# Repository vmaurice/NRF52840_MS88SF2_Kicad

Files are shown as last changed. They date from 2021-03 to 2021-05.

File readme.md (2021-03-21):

# NRF52840 avec le module MS88SF2

Carte schématisée et dessinée avec Kicad.

Cette carte possède le module MS88SF2 de Minew fabriqué avec un microcontrôleur NRF52840. L'objectif ici est d'avoir une carte Bluetooth faible en consommation branchée sur une batterie Lipo. 

Un module lm2902 est aussi présent afin d'amplifier les tensions de sortie des capteurs analogues.

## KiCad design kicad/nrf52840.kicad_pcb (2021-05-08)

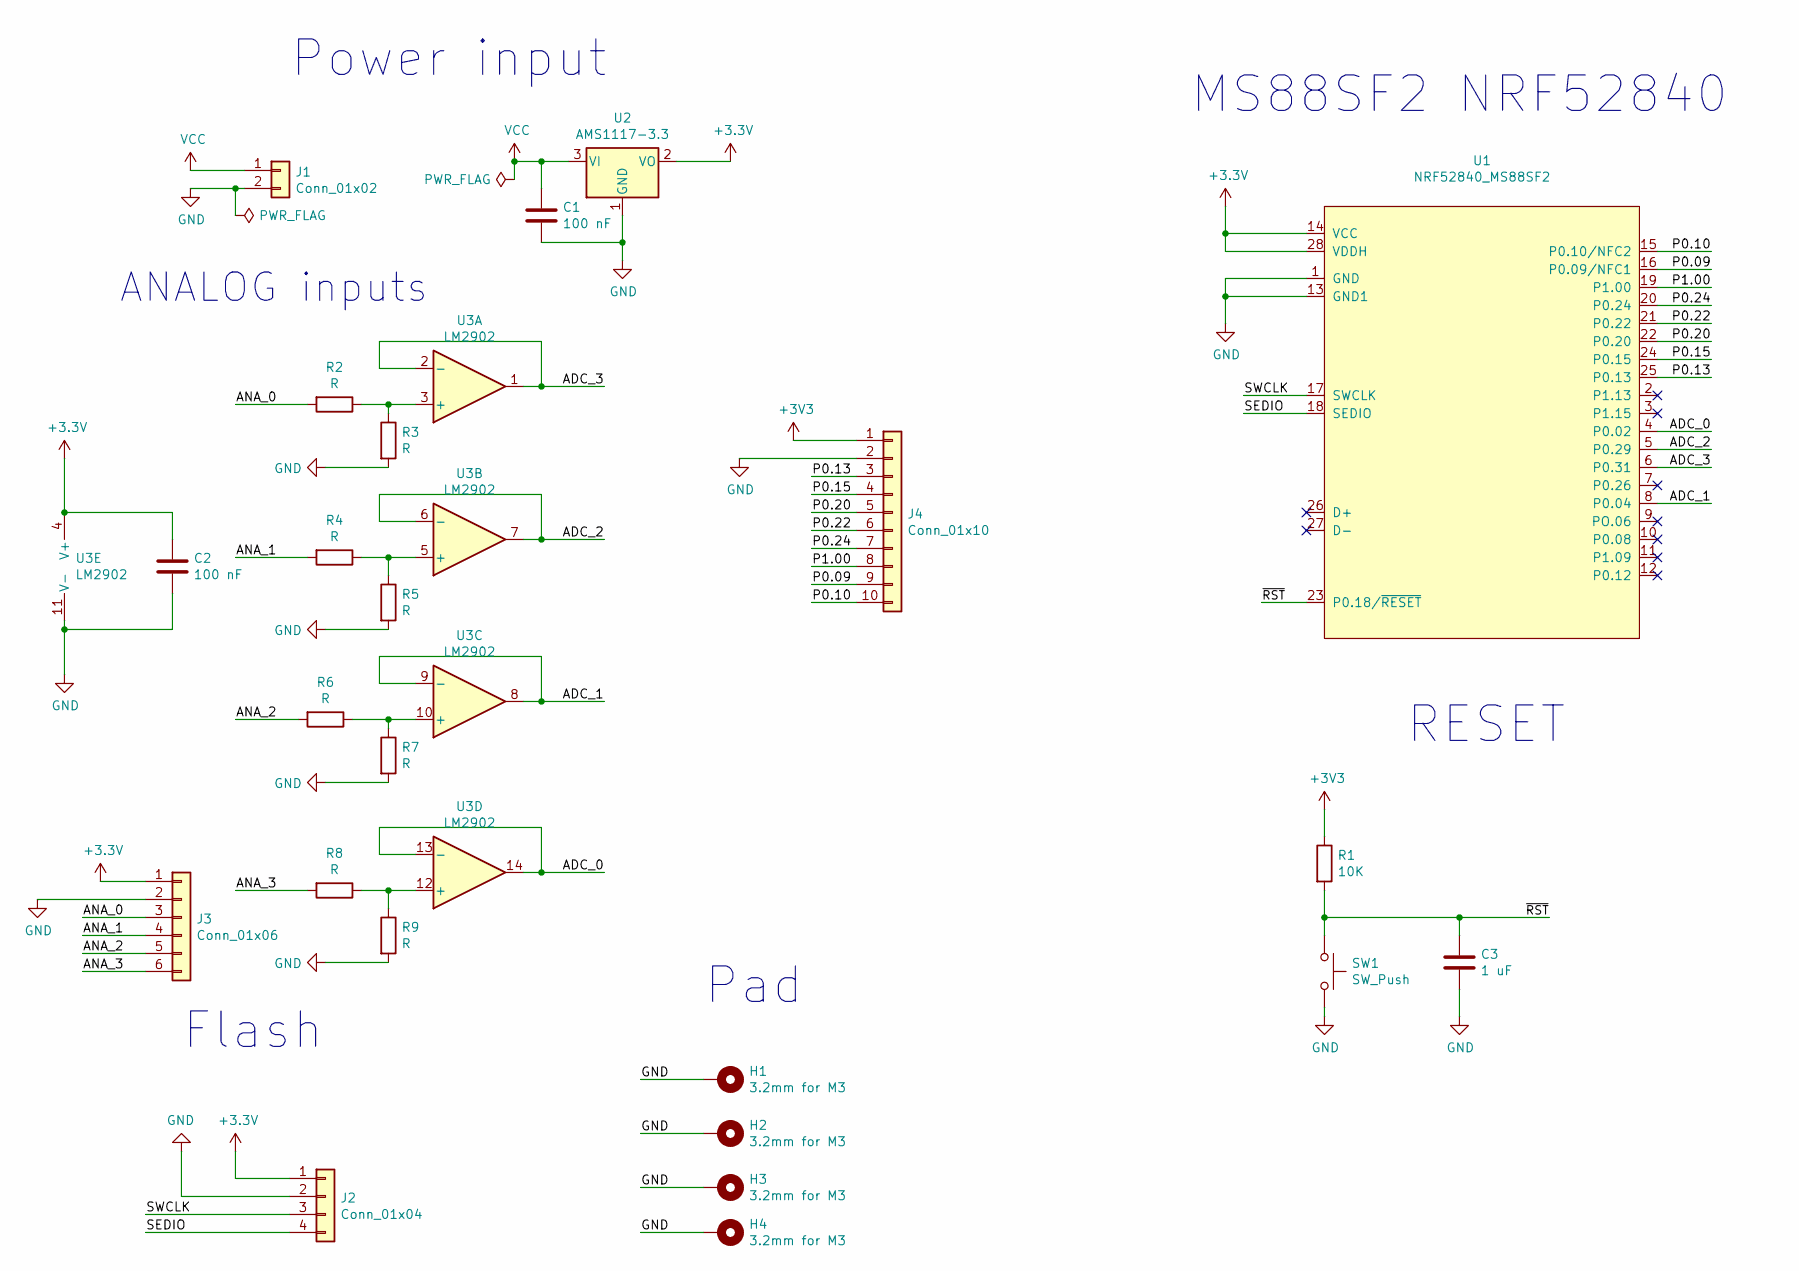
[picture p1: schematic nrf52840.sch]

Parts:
C1, C2: 100 nF; C_0805_2012Metric_Pad1.18x1.45mm_HandSolder
C3: 1 uF; C_0805_2012Metric_Pad1.18x1.45mm_HandSolder
H1, H2, H3, H4: 3.2mm for M3; MountingHole_3.2mm_M3_Pad_Via
J1: Conn_01x02; JST_XH_S2B-XH-A-1_1x02_P2.50mm_Horizontal
J2: Conn_01x04; PinHeader_1x04_P2.54mm_Vertical
J3: Conn_01x06; PinHeader_1x06_P2.54mm_Vertical
J4: Conn_01x10; PinHeader_1x10_P2.54mm_Vertical
R1: 10K; R_0805_2012Metric_Pad1.20x1.40mm_HandSolder
R2, R3, R4, R5, R6, R7, R8, R9: R; C_0805_2012Metric_Pad1.18x1.45mm_HandSolder
SW1: SW_Push; SW_SPST_SKQG_WithStem
U1: NRF52840_MS88SF2; MS88SF2
U2: AMS1117-3.3; SOT-223-3_TabPin2
U3: LM2902; SO-14_5.3x10.2mm_P1.27mm

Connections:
/ADC_0: U1.4 (P0.02), U3.13 (-), U3.14
/ADC_1: U1.8 (P0.04), U3.8, U3.9 (-)
/ADC_2: U1.5 (P0.29), U3.6 (-), U3.7
/ADC_3: U1.6 (P0.31), U3.1, U3.2 (-)
/ANA_0: J3.3, R2.2
/ANA_1: J3.4, R4.2
/ANA_2: J3.5, R6.2
/ANA_3: J3.6, R8.2
/P0.09: J4.9, U1.16 (P0.09/NFC1)
/P0.10: J4.10, U1.15 (P0.10/NFC2)
/P0.13: J4.3, U1.25 (P0.13)
/P0.15: J4.4, U1.24 (P0.15)
/P0.20: J4.5, U1.22 (P0.20)
/P0.22: J4.6, U1.21 (P0.22)
/P0.24: J4.7, U1.20 (P0.24)
/P1.00: J4.8, U1.19 (P1.00)
/SEDIO: J2.4, U1.18 (SEDIO)
/SWCLK: J2.3, U1.17 (SWCLK)
/~RST: C3.1, R1.2, SW1.1, U1.23 (P0.18/~RESET)
GND: C1.2, C2.2, C3.2, H1.1, H2.1, H3.1, H4.1, J1.2, J2.2, J3.2, J4.2, R3.2, R5.2, R7.2, R9.2, SW1.2, U1.1 (GND), U1.13 (GND1), U2.1 (GND), U3.11 (V-)
unnamed: R2.1, R3.1, U3.3 (+)
unnamed: R4.1, R5.1, U3.5 (+)
unnamed: R6.1, R7.1, U3.10 (+)
unnamed: R8.1, R9.1, U3.12 (+)
VCC: C1.1, J1.1, U2.3 (VI)

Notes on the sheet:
ANALOG inputs
MS88SF2 NRF52840
Power input
Flash
Pad
RESET

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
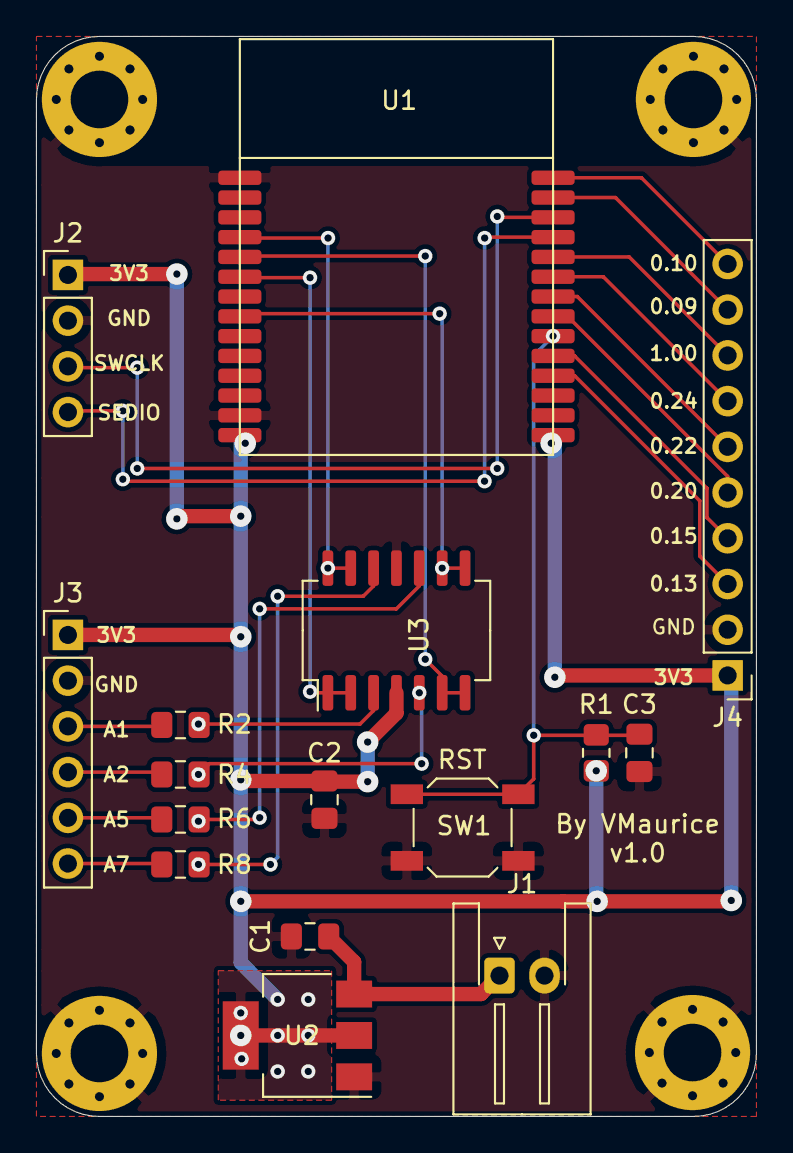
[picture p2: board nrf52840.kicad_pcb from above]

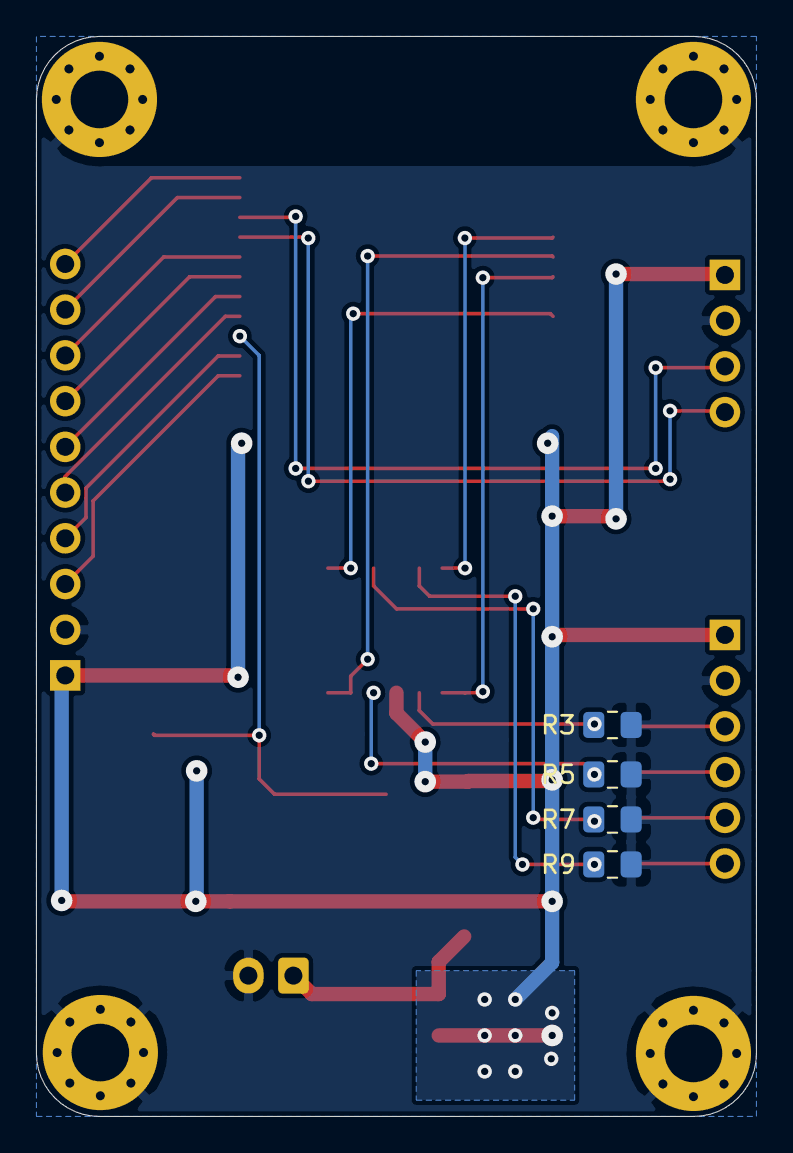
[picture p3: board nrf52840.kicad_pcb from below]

Board: 2 copper layers, 40.0 x 60.0 mm, 24 parts (4 on the bottom side), 26 nets.

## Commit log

2021-03-21 version 1
    [nrf52840.kicad_pcb, nrf52840.sch]
2021-05-05 add resistors for input analogs
    [nrf52840.kicad_pcb, nrf52840.sch]
